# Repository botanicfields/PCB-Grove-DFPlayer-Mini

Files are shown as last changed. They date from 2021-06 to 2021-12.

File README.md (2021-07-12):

# PCB-Grove-DFPlayer-Mini
a PCB to connect DFPlayer-Mini through Grove Connector

# DFPlayer-Mini 用 GROVE 接続基板
MP3 演奏モジュール DFPlayer-Mini を GROVE コネクタで簡単に接続するためのプリント基板です。フラッシュメモリ用 USB コネクタ、モニタースピーカー端子、ステレオ出力を備えます。押しボタンスイッチが 2 個あり、次の曲・前の曲の選択、長押しで音量増・減ができます。

販売委託（スイッチサイエンス）：  
https://www.switch-science.com/catalog/7310/

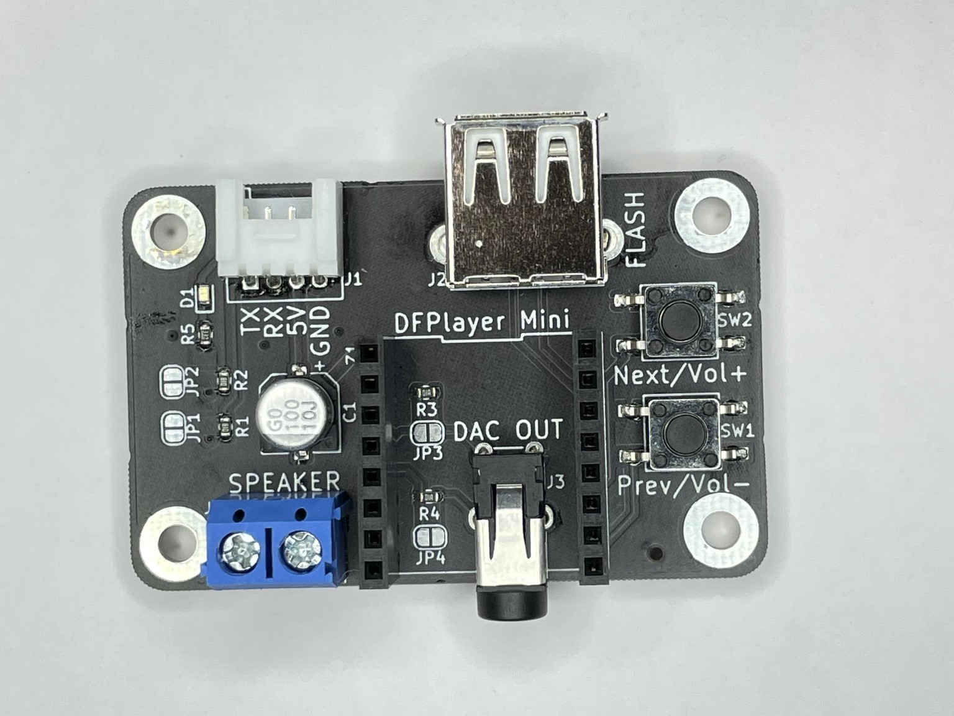
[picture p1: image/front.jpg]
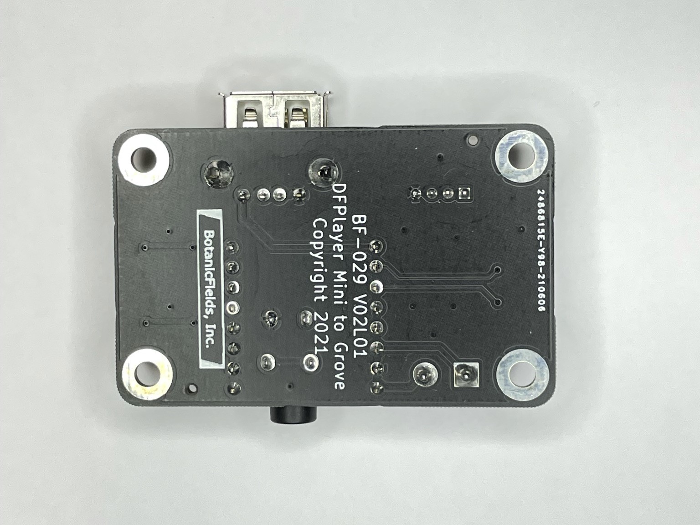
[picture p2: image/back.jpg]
 

## 特徴
- GROVE ケーブルで M5 シリーズのポート (UART 設定) に直結できます。
- 3.5mm ミニジャックからステレオ音声を出力できます。
- ターミナルブロックにスピーカー（モノラル）を接続できます。
- USB-A コネクタからフラッシュメモリの楽曲を演奏できます。
- 押しボタンスイッチが 2 個あります。次の曲・前の曲、長押しで音量増・減ができます。

## ご注意
- DFPlayer-Mini（スイッチサイエンスSKU:4291）は付属しません。
- GROVE の電源は 5V 専用です。信号 (UART) は 3.3V です。
- USB-A コネクタは USB フラッシュメモリ専用です。
- 5V 信号ヘの接続を考慮し、TX, RX に保護抵抗 (1kΩ) を入れています。JP1(TX), JP2(RX) をハンダでショートすることでバイパスできます。TX は 3.3V で出力する方向ですので、保護抵抗は不要です。実験中の接続ミスなどを考慮して使用することもできます。
- ステレオ出力には、保護抵抗 (100Ω) を入れています。出力レベルが不足する場合、JP3(R), JP4(L) をハンダでショートすることでバイパスできます。
- プリント基板単体の完成品です。ケースや足はありません。部品の足が剥き出しのため、絶縁材や四隅の穴にスペーサを取り付けるなどして、負傷、静電気破壊、机の傷などを防止ください。

## サンプルプログラム

DF-029.ino は、M5Atom 用です。M5Atom の GROVE ポートに DFPlayer-Mini を接続します。5 秒ごとに次の曲を演奏します。M5Atom のボタンを押すと、microSD・USB フラッシュの選択が切り替わります。

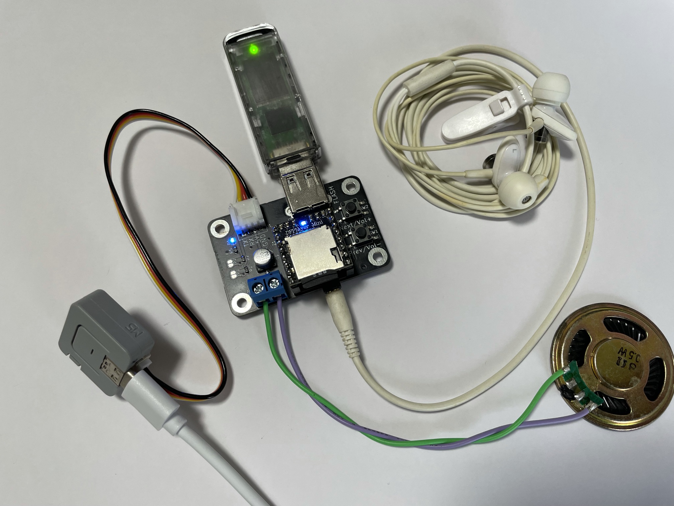
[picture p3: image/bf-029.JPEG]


## 内容物

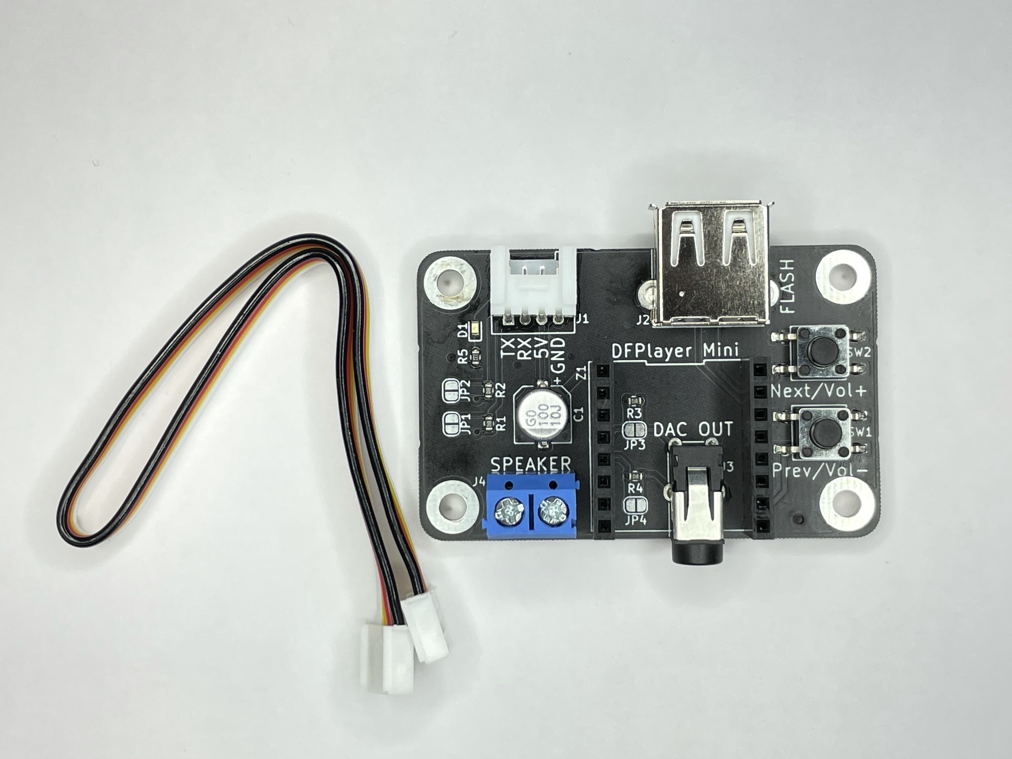
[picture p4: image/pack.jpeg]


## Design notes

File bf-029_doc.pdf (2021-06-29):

BF-029 V02

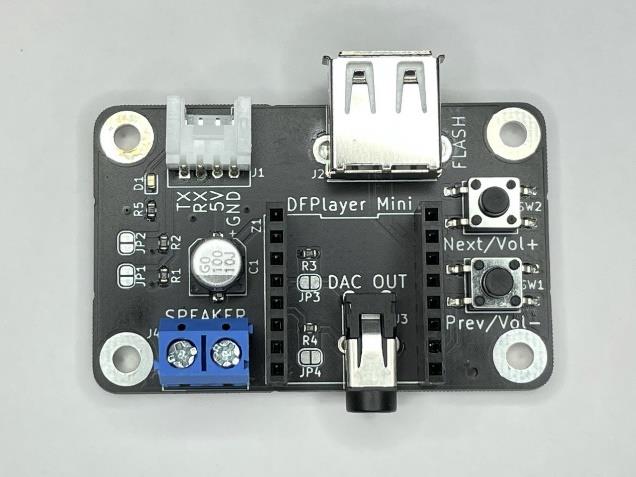
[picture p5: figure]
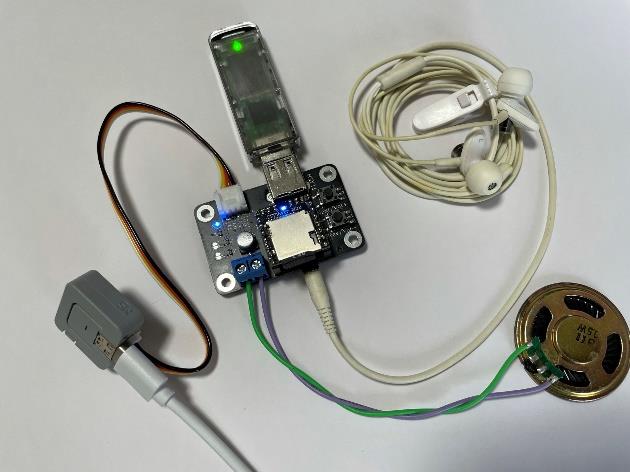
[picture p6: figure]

Copyright 2021 BotanicFields, Inc. 1

## DFPlayer-Mini 用 GROVE 接続基板

MP3 演奏モジュール DFPlayer-Mini を GROVE コネクタで簡単に接続するためのプリント基板です。フラ ッシュメモリ用 USB コネクタ、モニタースピーカー端子、ステレオ出力を備えます。押しボタンスイッチが 2 個あり、次の曲・前の曲の選択、長押しで音量増・減ができます。

1. 内容物（各１）
(1) プリント基板
(2) GROVE 互換ケーブル 20cm
(3) 説明書（本書）
※DFPlayer-Mini は付属しません。別途ご用意ください。
2. ご使用方法
(1) DFPlayer- Mini の取り付け
microSD 挿入口を手前にして差し込んでください。間違いが無いことを目視で再確認してから電源を 供給してください。
(2) スピーカーの接続
ターミナルブロックにスピーカーを接続できます。小型のドライバーが必要です。
(3) ラインアウトの接続
3.5mm ステレオミニジャックにライン出力を接続できます。イヤホンなども接続できます。
(4) GROVE ケーブルの接続
GROVE コネクタから 5V 電源を供給します。電源スイッチはありません。電源オンで LED が点灯 します。信号は 3.3V のシリアル RX, TX です。
(5) USB フラッシュメモリの接続
USB-A コネクタは、USB メモリ専用です。再生する楽曲について USB メモリとするか microSD と するかは、シリアル経由のソフトウェアで指定します。
(6) 押しボタンの操作
押しボタンで次の曲・前の曲を演奏できます。長押しで
音量増・音量減ができます。
(7) ソフトウェア
M5Atom へ接続してのソフトウェア例を GitHub（参考 情報を参照）に置きました。
3. ご注意
(1) 5V 信号ヘの接続を考慮し、TX, RX に保護抵抗 (1kΩ) を入れています。JP1(TX), JP2(RX) をハンダ でショートすることでバイパスできます。
(2) ステレオ出力には、保護抵抗 (100Ω) を入れています。出力レベルが不足する場合、JP3(R), JP4(L) を ハンダでショートすることでバイパスできます。
(3) プリント基板単体の完成品です。ケースや足はありません。部品の足が剥き出しのため、絶縁材や四隅の 穴にスペーサを取り付けるなどして、負傷、静電気破壊、机の傷などを防止ください。

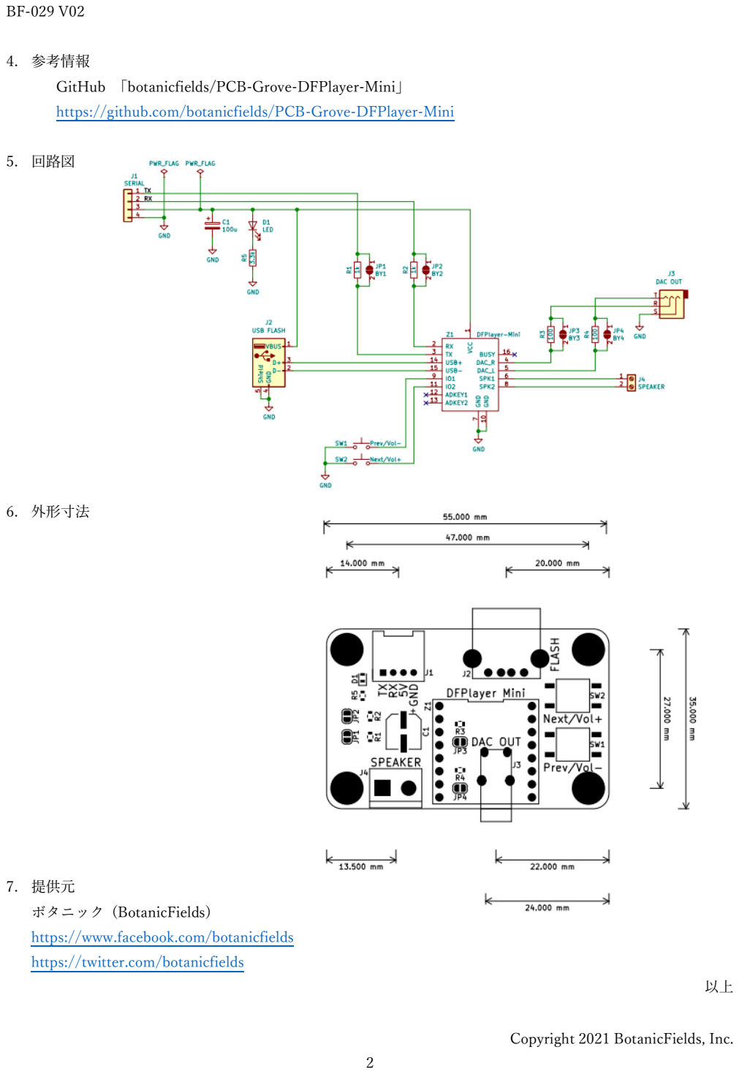
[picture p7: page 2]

BF-029 V02

Copyright 2021 BotanicFields, Inc. 2

4. 参考情報
GitHub 「botanicfields/PCB-Grove-DFPlayer-Mini」 https://github.com/botanicfields/PCB-Grove-DFPlayer-Mini
5. 回路図
6. 外形寸法
7. 提供元
ボタニック (BotanicFields)
https://www.facebook.com/botanicfieldshttps://twitter.com/botanicfields
以上

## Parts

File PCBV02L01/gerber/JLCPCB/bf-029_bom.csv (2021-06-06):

Comment | Designator | Footprint | LCSC
100u | C1 | bf:BF@CP_Elec_6.3x5.3 | C134749
LED | D1 | bf:BF@LED_0603_1608Metric | C72041
SERIAL | J1 | OPL_Connector:HW4-2.0-90D
USB FLASH | J2 | bf:BF@USB-A-5075AR
DAC OUT | J3 | bf:BF@MJ8435
SPEAKER | J4 | bf:BF@TerminalBlock_2_P5.08mm_d1.3mm
BY1 | JP1 | Jumper:SolderJumper-2_P1.3mm_Open_RoundedPad1.0x1.5mm
BY2 | JP2 | Jumper:SolderJumper-2_P1.3mm_Open_RoundedPad1.0x1.5mm
BY3 | JP3 | Jumper:SolderJumper-2_P1.3mm_Open_RoundedPad1.0x1.5mm
BY4 | JP4 | Jumper:SolderJumper-2_P1.3mm_Open_RoundedPad1.0x1.5mm
1k | R1,R2 | bf:BF@R_0603_1608Metric | C21190
100 | R3,R4 | bf:BF@R_0603_1608Metric | C22775
3.3k | R5 | bf:BF@R_0603_1608Metric | C22978
Prev/Vol- | SW1 | bf:BF@K2-6639SP | C83206
Next/Vol+ | SW2 | bf:BF@K2-6639SP | C83206
DFPlayer-Mini | Z1 | bf:BF@MP3-TF-16P

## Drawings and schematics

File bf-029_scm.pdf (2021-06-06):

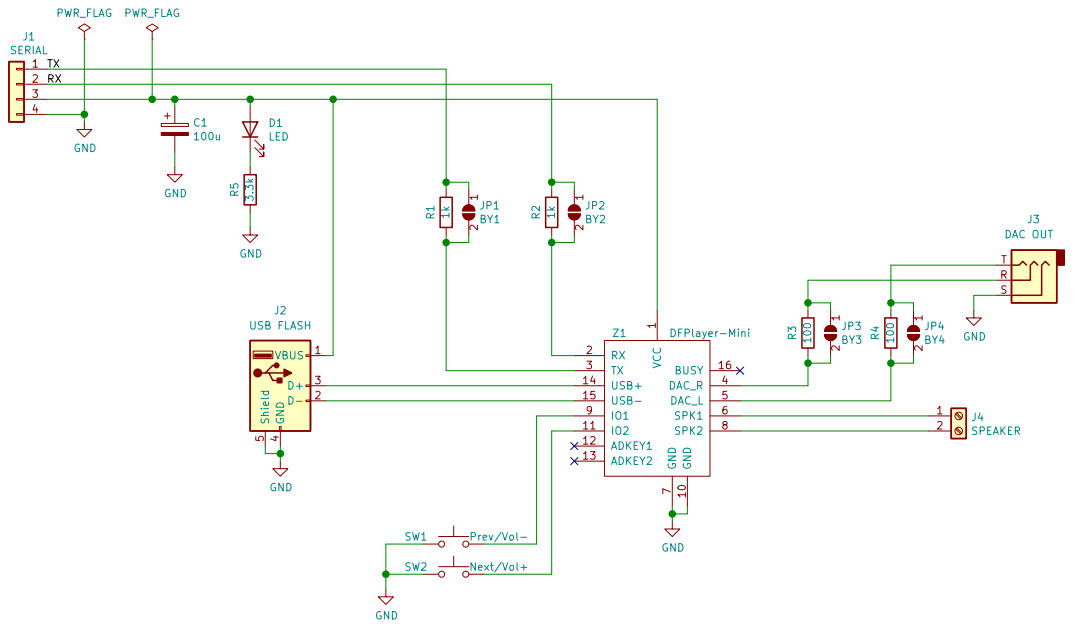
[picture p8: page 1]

J3 DAC OUT GND VCC

DFPlayer Mini to Grove
File: bf-029.sch Sheet: / Copyright 2021 BotanicFields, Inc.

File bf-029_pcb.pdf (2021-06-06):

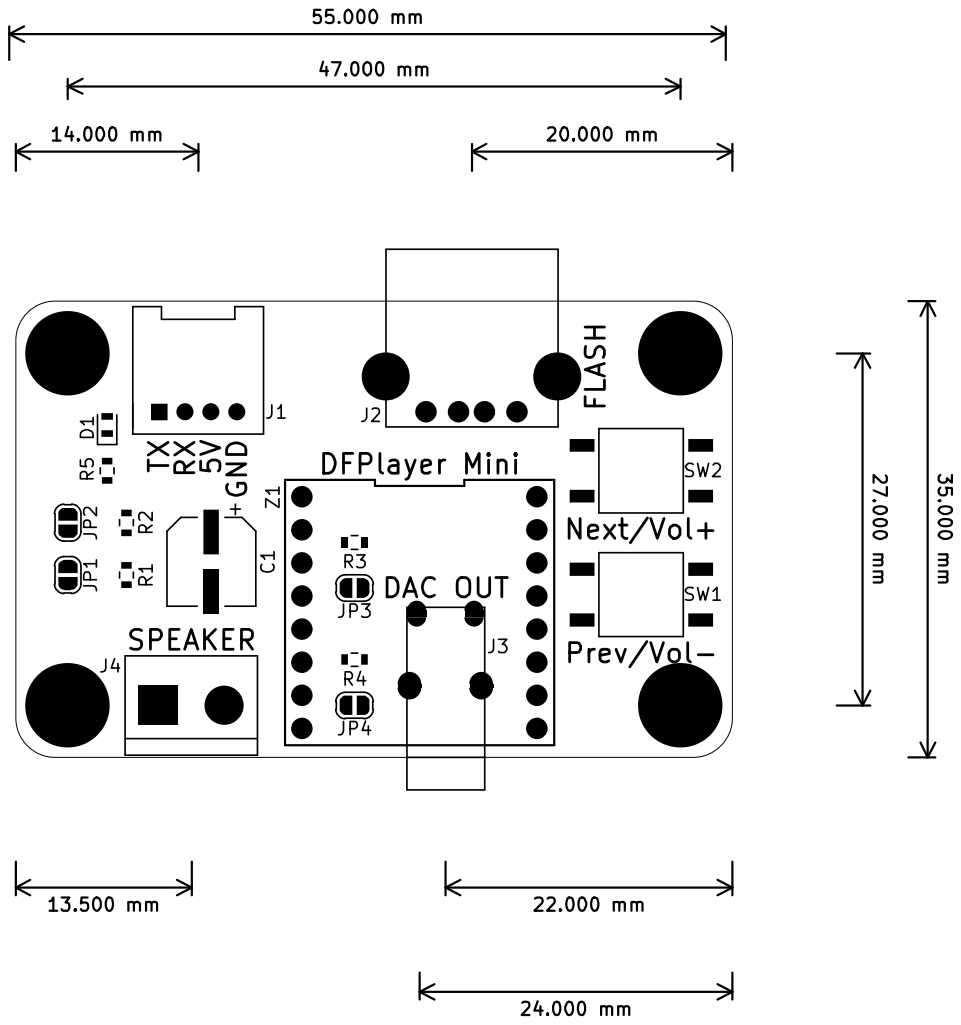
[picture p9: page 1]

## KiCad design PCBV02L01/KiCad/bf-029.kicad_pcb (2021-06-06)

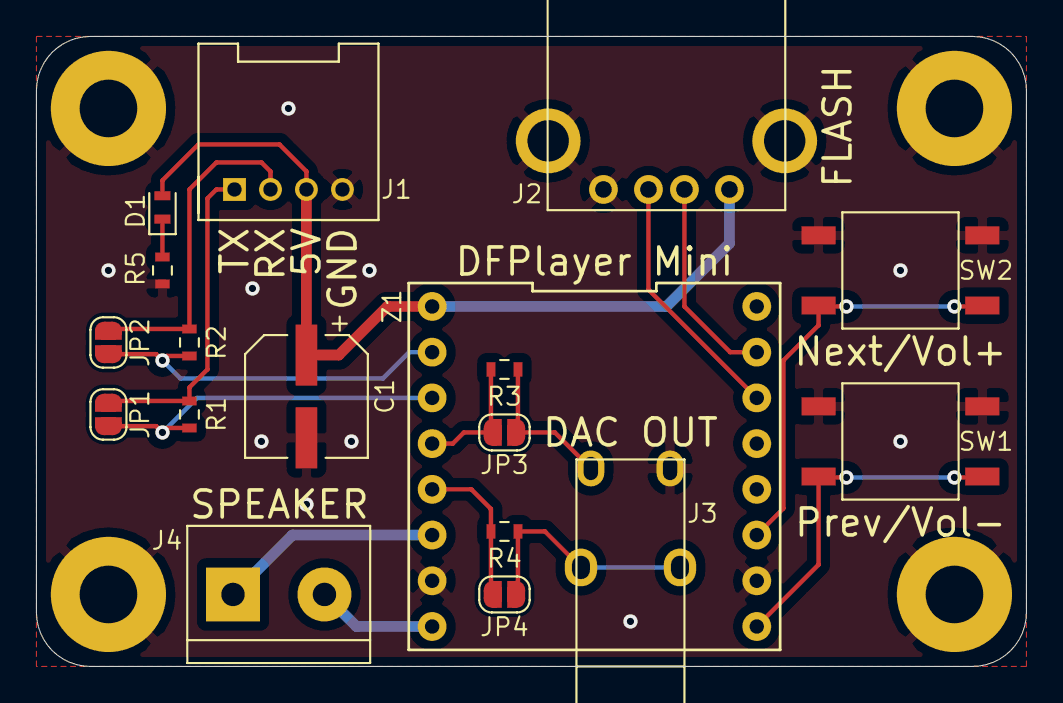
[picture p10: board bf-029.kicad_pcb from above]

Board: 2 copper layers, 55.0 x 35.0 mm, 18 parts (0 on the bottom side), 17 nets.

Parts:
C1: 100u; BF@CP_Elec_6.3x5.3
D1: LED; BF@LED_0603_1608Metric
J1: SERIAL; HW4-2.0-90D
J2: USB FLASH; BF@USB-A-5075AR
J3: DAC OUT; BF@MJ8435
J4: SPEAKER; BF@TerminalBlock_2_P5.08mm_d1.3mm
JP1: BY1; SolderJumper-2_P1.3mm_Open_RoundedPad1.0x1.5mm
JP2: BY2; SolderJumper-2_P1.3mm_Open_RoundedPad1.0x1.5mm
JP3: BY3; SolderJumper-2_P1.3mm_Open_RoundedPad1.0x1.5mm
JP4: BY4; SolderJumper-2_P1.3mm_Open_RoundedPad1.0x1.5mm
R1, R2: 1k; BF@R_0603_1608Metric
R3, R4: 100; BF@R_0603_1608Metric
R5: 3.3k; BF@R_0603_1608Metric
SW1: Prev/Vol-; BF@K2-6639SP
SW2: Next/Vol+; BF@K2-6639SP
Z1: DFPlayer-Mini; BF@MP3-TF-16P

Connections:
/RX: J1.2, JP2.1, R2.2
/TX: J1.1, JP1.1, R1.2
GND: C1.2, J1.4, J2.4, J2.5, J3.S, R5.1, SW1.1, SW2.1, Z1.7, Z1.10
unnamed: C1.1, D1.2, J1.3, J2.1, Z1.1
unnamed: D1.1, R5.2
unnamed: J2.2, Z1.15
unnamed: J2.3, Z1.14
unnamed: J3.R, JP3.1, R3.2
unnamed: J3.T, JP4.1, R4.2
unnamed: J4.1, Z1.6
unnamed: J4.2, Z1.8
unnamed: JP1.2, R1.1, Z1.3
unnamed: JP2.2, R2.1, Z1.2
unnamed: JP3.2, R3.1, Z1.4
unnamed: JP4.2, R4.1, Z1.5
unnamed: SW1.2, Z1.9
unnamed: SW2.2, Z1.11

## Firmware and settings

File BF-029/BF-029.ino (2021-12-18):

// copyright 2021 BotanicFields, Inc.
// Demonstration of DFPlayerMini
//
#include <M5Atom.h>
#include "BF_DfplayerMini.h"

DfplayerMini Dfpm;

const int loop_ms = 10;
unsigned int loop_last_ms  =  0;
unsigned int loop_count    =  0;

void setup()
{
  const bool serial_enable(true);
  const bool i2c_enable(true);
  const bool display_enable(true);
  M5.begin(serial_enable, !i2c_enable, display_enable);
  delay(3000);
  Serial.println("M5Stack begin");

  // Port UART
  const int serial2_rx(32);  // GPIO22
  const int serial2_tx(26);  // GPIO19
  Serial2.begin(9600, SERIAL_8N1, serial2_rx, serial2_tx);

  // for DFPlayer-Mini
  const bool feedback_enable(true);
  Dfpm.Begin(Serial2, !feedback_enable);
  delay(3000);
  Dfpm.Reset();
  delay(3000);

  loop_last_ms = millis();
  loop_count = 0;
}

void loop()
{
  M5.update();
  Dfpm.Update();

  static int dfpm_select(0);
  if (M5.Btn.wasReleased())
    switch (dfpm_select) {
      case  0: Dfpm.SelectDevice(0x01);  dfpm_select = 1;  break;
      case  1: Dfpm.SelectDevice(0x02);  dfpm_select = 0;  break;
      default: dfpm_select = 0;  break;
    }

  if (loop_count % 500 == 0)
    Dfpm.Next();

  delay(loop_ms + loop_last_ms - millis());
  loop_last_ms = millis();
  ++loop_count;
}

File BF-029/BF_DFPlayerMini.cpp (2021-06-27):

// copyright 2019 BotanicFields, Inc.
// DFRobot DFPlayerMini driver on ESP32/M5Stack
//
#include "BF_DfplayerMini.h"

DfplayerMini::DfplayerMini()
{
}

// &stream .. UART
// feedback .. 0: No, 1: Yes
void DfplayerMini::Begin(Stream &stream, bool feedback)
{
  m_stream = &stream;

  m_recv_timeout_ms = 1000;  // 1sec
  m_recv_start_ms   = 0;
  m_recv_count      = 0;
  m_expected        = 0;
  m_feedback        = 0;

  m_send_buf[0] = 0x7e;                  // constant: start byte
  m_send_buf[1] = 0xff;                  // constant: version
  m_send_buf[2] = 0x06;                  // constant: length
  m_send_buf[3] = 0;                     // command
  m_send_buf[4] = feedback? 0x01: 0x00;  // 0x01:enable feedback
  m_send_buf[5] = 0;                     // parameter MSB
  m_send_buf[6] = 0;                     // parameter LSB
  m_send_buf[7] = 0;                     // check sum MSB
  m_send_buf[8] = 0;                     // check sum LSB
  m_send_buf[9] = 0xef;                  // constant: end byte

  for (int i = 0; i < 10; ++i)
    m_recv_buf[i] = 0;

  m_dev_plug           = 0;
  m_dev_pull           = 0;
  m_finish_usb         = 0;
  m_finish_sd          = 0;
  m_device             = 0;
  m_error              = 0;
  m_status             = 0;
  m_volume             = 0;
  m_eq                 = 0;
  m_tracks_usb         = 0;
  m_tracks_sd          = 0;
  m_current_track_usb  = 0;
  m_current_track_sd   = 0;
  m_tracks             = 0;
  m_folders            = 0;

  Serial.print("[DFPlayerMini] Begin\n");
}

// call as often as possible to get response
void DfplayerMini::Update()
{
  while (m_stream->available() != 0) {
    uint8_t recv_data = m_stream->read();
    m_recv_buf[m_recv_count++] = recv_data;

    // check command code
    if (m_recv_count == 1) {
      if (recv_data == 0x7e)
        m_recv_start_ms = millis();
      else {
        m_recv_count = 0;
        Serial.printf("[DFPlayerMini] Update: skip %02x\n", recv_data);
      }
    }

    // entire command received
    if (m_recv_count == 10) {
      m_recv_count = 0;
      Receive();
    }
  }

  // check timeout
  if (m_recv_count != 0 && m_stream->available() == 0 && millis() - m_recv_start_ms > m_recv_timeout_ms) {
    m_recv_count = 0;
    Serial.print("[DFPlayerMini] Update: timeout during receiving\n");
  }
}

void DfplayerMini::Print()
{
  Serial.print("[DFPlayerMini] <online>");
  PrintDevice(m_device);

  Serial.print(" <status>");
  PrintStatus(m_status);

  Serial.printf(" <volume> %d <EQ>", m_volume);
  PrintEq(m_eq);

  if ((m_status & 0x0100) == 0) {  // not sleep
    if ((m_status & 0x0200) != 0) {  // SD online
      Serial.printf(" <SD tracks> %d <finished> %d <current> %d", m_tracks_sd,  m_finish_sd,  m_current_track_sd );
    }
    if ((m_status & 0x0100) != 0) {  // USB online
      Serial.printf(" <USB tracks> %d <finished> %d <current> %d", m_tracks_usb, m_finish_usb, m_current_track_usb);
    }
  }
  Serial.println();
}

bool DfplayerMini::Busy()
{
  if (m_feedback != 0 || m_expected != 0)
    return true;
  return false;
}

int DfplayerMini::Online()          { return m_device;            }
int DfplayerMini::Status()          { return m_status;            }
int DfplayerMini::Volume()          { return m_volume;            }
int DfplayerMini::Eq()              { return m_eq;                }
int DfplayerMini::TracksUsb()       { return m_tracks_usb;        }
int DfplayerMini::TracksSd()        { return m_tracks_sd;         }
int DfplayerMini::CurrentTrackUsb() { return m_current_track_usb; }
int DfplayerMini::CurrentTrackSd()  { return m_current_track_sd;  }
int DfplayerMini::Tracks()          { return m_tracks;            }
int DfplayerMini::Folders()         { return m_folders;           }

void DfplayerMini::Reset()                                { Send(0x0C);                }
void DfplayerMini::Sleep()                                { Send(0x0A);                }

void DfplayerMini::Play()                                 { Send(0x0D);                }
void DfplayerMini::Pause()                                { Send(0x0E);                }
void DfplayerMini::Stop()                                 { Send(0x16);                }
void DfplayerMini::Next()                                 { Send(0x01);                }
void DfplayerMini::Previous()                             { Send(0x02);                }
void DfplayerMini::Random()                               { Send(0x18);                }
void DfplayerMini::Repeat(int turn_off)                   { Send(0x19, turn_off);      }

void DfplayerMini::PlayRoot(int track)                    { Send(0x03, track);         }
void DfplayerMini::PlayFolder(int folder, int track)      { Send(0x0F, track, folder); }
void DfplayerMini::PlayFolderMp3(int track)               { Send(0x12, track);         }
void DfplayerMini::playFolder3000(int folder, int track)  { Send(0x14, track, folder); }

void DfplayerMini::RepeatRoot(int track)                  { Send(0x08, track);         }
void DfplayerMini::RepeatRootAll(int start)               { Send(0x11, start);         }
void DfplayerMini::RepeatFolder(int folder)               { Send(0x17, folder);        }

void DfplayerMini::InsertAdvert(int track)                { Send(0x13, track);         }
void DfplayerMini::Resume()                               { Send(0x15);                }

void DfplayerMini::IncreaseVolume()                       { Send(0x04);                }
void DfplayerMini::DecreaseVolume()                       { Send(0x05);                }
void DfplayerMini::SetVolume(int volume)                  { Send(0x06, volume);        }
void DfplayerMini::SetEq(int eq)                          { Send(0x07, eq);            }

void DfplayerMini::SetDac(int turn_off)                   { Send(0x1A, turn_off);      }
void DfplayerMini::SetAudio(int gain, int enable)         { Send(0x10, gain, enable);  }
void DfplayerMini::SelectDevice(int device)               { Send(0x09, device);        }

void DfplayerMini::QueryDevice()                          { Send(0x3F);                }
void DfplayerMini::QueryStatus()                          { Send(0x42);                }
void DfplayerMini::QueryVolume()                          { Send(0x43);                }
void DfplayerMini::QueryEq()                              { Send(0x44);                }

void DfplayerMini::QueryCurrentTrackOfUsb()               { Send(0x4B);                }
void DfplayerMini::QueryCurrentTrackOfSd()                { Send(0x4C);                }

void DfplayerMini::QueryTracksInUsb()                     { Send(0x47);                }
void DfplayerMini::QueryTracksInSd()                      { Send(0x48);                }
void DfplayerMini::QueryTracks(int folder)                { Send(0x4E, folder);        }
void DfplayerMini::QueryFolders()                         { Send(0x4F);                }
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
